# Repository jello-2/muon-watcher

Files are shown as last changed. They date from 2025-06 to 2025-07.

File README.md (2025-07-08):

# Muon Watcher

A Hackclub Apex project by Brian Zhang, Daniel Zhang, and Eugene Lee

## Project Motivation

In Physics, a prominent example of special relativity used is the Muon; a particle that travels at high enough speeds to experience relativistic effects. This project aims to observe time dilation in muons, utilizing scintillators and sensors to detect the change in rate of muons detected. The project hopes to confirm / explore the Pfotzer maximum, where experimentation and theory have shown that a maximal rate of particle detection occurs at ~29km.

## Project outline

We initially expected that the relativistic effects would mean that a larger rate would be observed at the bottom, and a lesser upwards, but sources such as
https://www.unco.edu/nhs/physics-astronomy/pdf/2018CSGCEclipse.pdf
show that there exists a particular curve for this data, the Pfotzer curve. Thus, this experiment intends to not only observe the Muons themselves, but also whether if the Pfotzer curve exists in our own experimentation

Muon detection is done through the CosmicWatch Desktop Muon Detector (https://github.com/spenceraxani/CosmicWatch-Desktop-Muon-Detector-v2), to which it will be modified to include other sensors.

## Work Splits:
| Person | work accomplished |
| ---| ---|
| Eugene | soldering, wiring, first & second box assembley, initial version 1 code, research, version 2 code debugging, project design |
| Daniel | soldering, camera mount CAD, first box (window creation, camera mounting), version 2 Oled + altimeter + SD card code, parts ordering |
| Brian | second box component assembly, battery holder, research, project design, box testing, component wiring|

A more detailed presentation can be viewed here: https://docs.google.com/presentation/d/1ZBc04pf7R1xf7GHWZV_NUtK7q8jfDxB4UwPaJ63R6cA/edit?usp=sharing
## Components
- Scintillator
- Altimeter
- Arduino
- Battery packs
- Styrofoam box
- Jumper Wires
- OLED screen
- PCB + LED

## Progress

| Step | Description | Progress|
| --- | --- | --- |
| 1. Research | Muon fundamentals, components required, altitude-rate theory  | Complete|
| 2. Building| Components delivered and to be soldered, planning of location of parts and sensors | Complete |
| 3. Testing  | Make sure components and code are foolproof, meet with engineers | Complete |
| 4. Official Run | Attached to weatherballoon| Complete |
|5. Data analysis and results| Plotting with tools such as Matplotlib | -|

## Acknolwedgements

A big thank you to Hack club for providing this unique opportunity!

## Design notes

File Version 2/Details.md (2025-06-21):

# Version 2

## Code
Code adapted from https://github.com/jgOhYeah/NonOfficial-StuffForCosmicWatchMuonDetectors/tree/master/Arduino%20Code/MuonDetector

What differs from Version 1:
- Accomodate a BMP 180 Altimeter 
- Write to SD card & Display on OLED
- Memory reduction to fit onto Arduino Nano.

Notable details:

Spencer Axani's code for writing to an SD card + displaying on an OLED was too large computationally to push and upload onto the Arduino Nano. A solution was found through jgOhYeah's repository, saving space on the Nano. We then implemented the BMP180 altimeter in the code, which also required us to cut down on even more libraries to accomodate the sensor's library and functionality. 

## Hardware
We found that the initial idea of trying to put a Camera, along with a window and the electronics would be unfeasible for the given weight requirements. Instead, we cut out a new box, and utilized jumper wires to route the OLED, LED, master switch, all to the wall of the box. We removed the camera.

Notably:
 
We first tried an Apeman A77 action camera, but the battery life would not last the ~ 3 hours required for launch. We then attempted to power it through the micro-usb on the side, which was wired to a battery pack. This did not seem to power either. Eventually, we gave up and tried a Raspberry Pi Zero W, with a camera module.

Our Raspberry Pi Zero W would not connect to the Wifi nor SSH, making accessability impossible with it. We also ditched this idea.

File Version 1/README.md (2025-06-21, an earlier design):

# Version 1
## Code

Source Arduino code gathered from: https://github.com/spenceraxani/CosmicWatch-Desktop-Muon-Detector-v2

This code was taken directly from Spencer Axani and the CosmicWatch Muon Detector. It is capable of EITHER displaying to the OLED or writing to the SD card. We were mainly unsatisfied with its capabilities: we wanted altimeter support to confirm the Pfotzer curve, as well as for it to both be displayed on the screen and written to the SD card. This was resolved in Version 2.

## Hardware

For the hardware, our PCB and Scintillator were followed near-identically (except for its tuning) from the repository. The case was cut from a differently sized styrofoam box, and we tried adding a polycarbonate window. This proved to be too heavy, and posed potential adhesion issues. Therefore, it was also scrapped. A camera mount was CADed as well.

Simiarily, a shell for the PCB was also designed, but then removed, since it was not only too heavy, but inhibited the access to sensors.

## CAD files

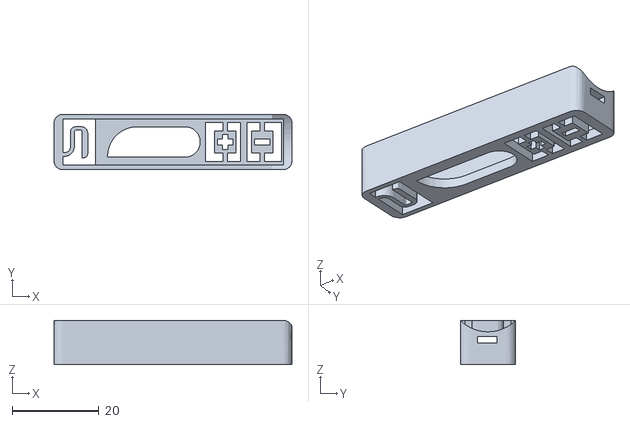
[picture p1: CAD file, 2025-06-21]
CAD/Version 1/battery pack.stl
54.9 x 12.8 x 10.2

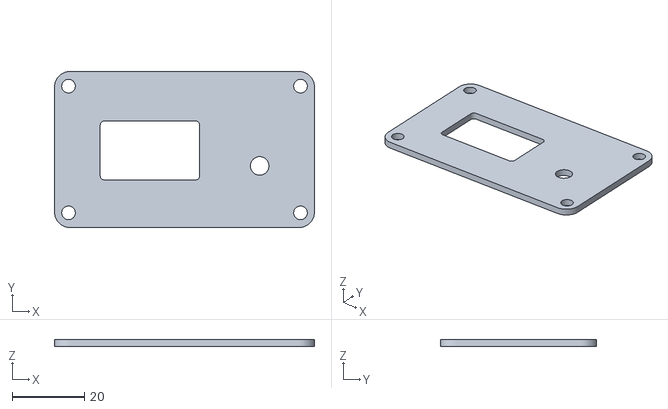
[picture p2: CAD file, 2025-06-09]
CAD/Version 1/V1 Case.stl
71.8 x 43.1 x 2.00

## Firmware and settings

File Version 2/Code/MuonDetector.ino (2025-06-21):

#include "defines.h"
#include "strings.h"

#include <Adafruit_BMP085.h>
#include <Wire.h>
#include <U8x8lib.h>
#include <SD.h>

Adafruit_BMP085 bmp;
File myFile;

U8X8_SSD1306_128X64_NONAME_HW_I2C u8x8(U8X8_PIN_NONE);

unsigned long count = 0;
float sipmVoltage = 0;

unsigned int startTime = 0;
unsigned long totalDeadtime = 0;

bool isSDCard = false;
char separatorChar = ' ';

// Declare charBuffer globally for reuse across functions
char charBuffer[60] = "";

const long double cal[] = {-9.085681659276021e-27, 4.6790804314609205e-23, -1.0317125207013292e-19,
  1.2741066484319192e-16, -9.684460759517656e-14, 4.6937937442284284e-11, -1.4553498837275352e-08,
   2.8216624998078298e-06, -0.000323032620672037, 0.019538631135788468, -0.3774384056850066, 12.324891083404246};
   
   
float get_sipm_voltage(float adc_value) {
  float v = 0;
  for (int i = 0; i < 12; i++) v += cal[i] * pow(adc_value, 11 - i);
  return v;
}

void setup() {
  analogReference(EXTERNAL);
  ADCSRA &= ~(bit(ADPS0) | bit(ADPS1) | bit(ADPS2));
  ADCSRA |= bit(ADPS0) | bit(ADPS1);
  pinMode(3, OUTPUT);

  Serial.begin(9600);

  u8x8.begin();
  u8x8.setFlipMode(1);
  u8x8.setPowerSave(0);
  u8x8.setFont(u8x8_font_chroma48medium8_r);

  bmp.begin(); // Initialize BMP sensor

  strcpy_P(charBuffer, cosmicString);
  u8x8.draw2x2String(0, 0, charBuffer);
  strcpy_P(charBuffer, watchString);
  u8x8.draw2x2String(6, 2, charBuffer);

  if (SD.begin(PIN_SD_CARD)) {
    strcpy_P(charBuffer, sdPresent);
    u8x8.clear();
    u8x8.draw1x2String(0, 0, charBuffer);
    strcpy_P(charBuffer, loggingTo);
    u8x8.draw1x2String(0, 2, charBuffer);

    isSDCard = true;
    openLogFile(charBuffer);
    u8x8.draw1x2String(0, 4, charBuffer);
  } else {
    strcpy_P(charBuffer, noSdCard);
    u8x8.clear();
    u8x8.draw1x2String(0, 0, charBuffer);
  }

  if (isSDCard) {
    //myFile.print("细微探深");
    myFile.println();
  }


  delay(2000);

  if (isSDCard) {
    strncpy_P(charBuffer, txtHeader, 50);
    myFile.print(charBuffer);
    strcpy_P(charBuffer, txtHeader + 50);
    myFile.println(charBuffer);
    myFile.flush();
  }

  PORTD &= ~PIN_LED;

  u8x8.clear();
  strcpy_P(charBuffer, totalCount);
  u8x8.draw1x2String(0, 0, charBuffer);  // Count or other text on left

  float initialAlt = bmp.readAltitude();
  char altStr[6];
  snprintf(altStr, sizeof(altStr), "%4dm", (int)initialAlt);

  byte altLen = strlen(altStr);
  byte startCol = 16 - altLen;

  u8x8.draw1x2String(startCol, 0, altStr);

  analogRead(A0);
  startTime = millis();
}

void loop() {
  if (analogRead(A0) > THRESHOLD_SIGNAL) {
    int detectionADC = analogRead(A0);
    
    float initialAlt = bmp.readAltitude();
    

    Serial.println(detectionADC); // Print only the ADC value

    unsigned long timeStamp = micros();
    unsigned long timeDetecting = millis() - startTime;

    PORTD |= PIN_LED;

    float temperatureC = (((analogRead(PIN_TEMPERATURE) * 2) * (1650.0 / 1024)) - TEMPERATURE_SENSOR_OFFSET) / 10.0;

    count++;
    sipmVoltage = get_sipm_voltage(detectionADC);

    char countString[11], timeString[11], adcString[5], sipmVString[7], deadtimeString[11], tempCString[7];

    ultoa(count, countString, 10);
    ultoa(timeDetecting, timeString, 10);
    itoa(detectionADC, adcString, 10);

    byte decimalPlaces = (sipmVoltage >= 100 || sipmVoltage < 0) ? 0 : 1;
    dtostrf(sipmVoltage, 1, decimalPlaces, sipmVString);

    ultoa(totalDeadtime, deadtimeString, 10);
    dtostrf(temperatureC, 1, 1, tempCString);

    if (isSDCard) {
      myFile.print(countString);      myFile.print(separatorChar);
      myFile.print(timeString);       myFile.print(separatorChar);
      myFile.print(sipmVString);      myFile.print(separatorChar);
      myFile.print(tempCString);      myFile.print(separatorChar);
      myFile.print(initialAlt);
      myFile.println();
      myFile.flush();
    }

    //drawing
    u8x8.clear();
    strcpy_P(charBuffer, totalCount);
    u8x8.draw1x2String(0, 0, charBuffer);  // Count or other text on left

    char altStr[7];
    snprintf(altStr, sizeof(altStr), "%4dm", (int)initialAlt);
    byte startCol = 16 - strlen(altStr);
    u8x8.draw1x2String(startCol, 0, altStr);

    strcpy_P(charBuffer, rateString);
    u8x8.draw1x2String(0, 2, "Time:");
    u8x8.draw1x2String(0, 6, charBuffer);

    for (byte i = 0; i < 15; i++) {
      memcpy_P(charBuffer, barScaleB + i * 8, 8);
      u8x8.drawTile(i + 1, 5, 1, charBuffer);
    }    
    //end drawing

    PORTD &= ~PIN_LED;

    while (analogRead(A0) > THRESHOLD_RESET) {continue;}
    totalDeadtime += (micros() - timeStamp) / 1000.;
  }

  updateTime();
}

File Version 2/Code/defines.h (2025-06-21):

/*defines.h
 * Code adapted from Spencer Axiani's original software and designs by Jotham Gates
 * This file allows the software to be customised without having to scroll through many lines of code.
 * See MuonDetector.ino for more information
 */
#define FIRMWARE_VERSION "2.3.2"
//Pins
#define PIN_TEMPERATURE A3
#define PIN_LED B00001000 //Bitmap of pin D3 - Does not use digitalWrite to save time and memory
#define PIN_SD_CARD 10
#define PIN_COINCIDENCE B01000000 //Bitmap of pin D6
#define OLED_RESET 10

//Interfaces to use. Comment out to disable non required ones. This will speed the detector up a little bit.
//If both serial and the sd card are not required, the arduino will not bother to take readings from the temperature sensor or format the values as a string.
//If the screen is used, it will be updated once per second.
#define USE_SCREEN //Whether to include the library and code for driving the oled display or not
#define USE_SD_CARD //Whether to include the library and code for writing to the sd card
#define THRESHOLD_SIGNAL 50
#define THRESHOLD_RESET 25
#define THRESHOLD_LARGE 180


//General
#define NUMBER_FILES_TO_DELETE 5 //If the sd card if full, start at the beginning and delete 5 more files ahead
#define FILENAME_NUMBER_START_POS 5 //Position of the hundreds char in the filename
#define MAX_FILES 200 //200 temp, 10 for testingMaximum file number before rolls back to 0 Needs to be less then 255 - NUMBER_FILES_TO_DELETE (in this case 250)
#define SCREEN_UPDATE_INTERVAL 1000 //ms between updating the screen
#define TEMPERATURE_SENSOR_OFFSET 500 //The voltage (in mV) produced by the temperature sensor when the temperature is 0.

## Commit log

2025-06-08 Added arduino files from today's testing
2025-06-20 HOLY HELL ITS FIXED NOW ALTITUDE BMP BABYYY OPTIMIZATION
    [MuonDetector.ino, defines.h, oled.ino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]
2025-06-21 Renaming and more reorganization
    [V1 Case.stl]
